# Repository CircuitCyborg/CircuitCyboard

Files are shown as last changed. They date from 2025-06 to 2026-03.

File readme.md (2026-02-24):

View the assembled board in 3D and download the most up to date files including the fully printable version at https://cad.onshape.com/documents/f318f11670ed4c30b1b2f4fc/w/6b6f3f7c04ff2543b1a0db1e/e/09f2c27e2ae763cc1f32f98d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



This is the CircuitCyboard; A 153% keyboard made for video editors or anyone who is completely insane. I decided to design this board when I started editing videos for my robotics team. It took me approximately 47 hours to complete due to having to essentially complete two keyboards to complete a single set. 

HOW LONG DID THIS KEYBOARD TAKE TO DESIGN?
This keyboard took about 47 hours to design due to being on an FTC team that made it to the World Championship along with the rest of my school and what other "life" I have.

Here's one of my mid-project updates:

March 4, 2025
It's been a while since I have really had enough time to make some progress on my HackBoard. I was able to find some time this afternoon to nearly finish the project. Here's a little overview of where I'm at, but first for those who didn't see my original plans a few months ago: I do a decent amount of video editing for my FTC team and some personal projects. Back in October during HackpadV1, I created a little 3x3 macropad with 2 rotary encoders. It has sped up my editing by probably 35%. I really like efficiency, so I started looking into the BlackMagicDesign editor keyboard.



Unfortunately, that keyboard costs $595. That's about $535 out of my price range on a normal month, and this year about $575 out of my range. When Alex announced HackpadV2 I knew I wanted to attempt to design my own version. But why stop designing when I have the exact same hardware design as BlackMagicDesign? Why not create my own unique one of a kind piece?
Introducing The CircuitCyboard: @CircuitCyborg's very own editing keyboard. It is a one of a kind piece that just so happens to resemble the Blackmagicdesign Editor Keyboard if it was a split keyboard. Why is it split you may ask? Because there are too many rows and columns for a single Raspberry Pi (Or in this case, a single Orpheus Pico). So in order to get two MCU's, Alex's requirement was that I make it a split keyboard. Now on to the update: The PCB is nearly finished. I need to add a few decorations to the silkscreen and make sure all of the stabilizer mounts will actually work (Who am I kidding, I'm not going to do that), then I think both PCB's will be ready to export. Both Cases are complete I think. I need to go through and make sure everything is 100% correctly done and finished. Today I decided I wanted to try and do the firmware in POG so that I can more easily change keys throughout the boards use. So I think firmware is complete (Enough until I get the hardware) and ready to be dropped onto the MCU's. Unfortunately, I don't believe the grants will be enough to cover everything so I may have to add some of my own funds into it. I guess that means I have to wait another month before I can buy that mic. Oh Well. It's worth it.

Here is what the original design looked like:






Here is another update now that I am getting ready to submit:

June 2, 2025
It's been another 3 months since my last update. I have almost completely redone the whole keyboard. The only things that are still the same are the base keys and their positions, and the basic idea of having a mega split using two Orpheus Picos. Since the last update I decided that instead of using a completely 3D Printed case, I wanted an acrylic top. I then redesigned the case after redesigning the PCB so that the MCU on the left half was vertical instead of horizontal so that the chord would plug in to the top instead of the side. I then added three more rotary encoders to the left half. Next I designed the case to have an acrylic top. After some thought, I am considering cutting the base of the case out of wood after I confirm it fits with a 3D Printed version. Assuming it does, I will find a nice piece of wood to cut it out of and use my robotics team's CNC router to cut it out. Next I started sourcing parts for my board. At this point I still haven't ordered parts yet, but I am trying my best to not order any parts directly from AliExpress because I do not trust that site or any of its sibling sites. Do to this, parts may cost a little more for me, but occasionally, I can find better quality parts as well from Amazon over what can be found at AliExpress. I think that's all for this update. Signing off for now, Circuitcyborg.

Here is what the semi-final design looks like:













I have now spent the last few days putting together all of the files and getting pricing down and finalizing part selections for the BOM and to create my Repo. Next up is the info for the firmware.

Firmware was kept simple for this because although editing the firmware on my macropad has been relatively simple, I want an even simpler way to edit the firmware for this. Introducing POG, a firmware editor/writer for keyboards based off of KMK. All you need to do is install POG on your device and install the firmware I have provided onto your Raspberry Pi's, then you will be able to edit the keyboard functions from within POG.

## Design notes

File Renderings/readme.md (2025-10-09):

Renderings of the CircuitCyboard 153% Keybaord
























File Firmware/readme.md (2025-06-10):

Firmware was kept simple for this because although editing the firmware on my macropad has been relatively simple, I want an even simpler way to edit the firmware. Introducing POG, a firmware editor/writer for keyboards based off of KMK. I have not tested it yet, but the idea is that anyone can install this firmware on it, then install POG and easily be able to edit the firmware on it. I'll update once I have the time to test this theory.





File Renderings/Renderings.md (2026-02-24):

Renderings of the CircuitCyboard 153% Keybaord


























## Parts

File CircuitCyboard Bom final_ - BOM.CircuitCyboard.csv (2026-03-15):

Total Per Part Category |  | Quantity Needed | Total Cost Pre-Tax | Component | Supplier | Link
$76.15 | PCB | 1 | $36.65 | Left PCB | JLCPCB | N/A
 |  | 1 | $39.50 | Right PCB | JLCPCB | N/A
$45.96 | Switches - $0.50/Switch | 2 | $22.98 | Gateron G Blue Pro 3.0 Switches | Aliexpress | https://www.aliexpress.us/item/3256804371339613.html?
$12.77 | Fasteners - Total $15 | 1 | $5.48 | GSJ Threaded Heat Set Inserts | Aliexpress | https://www.aliexpress.us/item/3256804189121253.html?
 |  | 1 | $7.29 | M3 Button Head Socket Cap Bolts | Aliexpress | https://www.aliexpress.us/item/3256806973435795.html?
$11.69 | Keycaps - $25 | 1 | $7.80 | Keycaps 126 Keys Cherry Profile | Aliexpress | https://www.aliexpress.us/item/3256807135386098.html?
 |  | 1 | $3.89 | 24 Pc DSA Profile 1u keycaps | Aliexpress | https://www.aliexpress.us/item/3256807298018561.html?
$23.77 | Stabilizers - $20 | 1 | $23.77 | Durock Stabilizers V3 80% Kit | Aliexpress | https://www.aliexpress.us/item/3256802006071565.html?
$11.81 Including Shipping | Misc Electronics - $15 | 1 | $3.17 | Alpsalpine EC11E Rotary Encoder | Aliexpress | https://www.aliexpress.us/item/3256805796819763.html?
 |  | 2 | $8.64 | LGE 1N4148 Diodes | Aliexpress | https://www.aliexpress.us/item/3256802153601411.html?
N/A | MCU | 2 | N/A | Orpheus Picos | Hack Club | N/A
$9.95 | Other Parts | 1 | $9.95 | Polycarbonate Sheet 12x18 1/16" | Amazon | https://www.amazon.com/Polycarbonate-Plastic-Robotics-Industrial-Shatterproof/dp/B07MQTDF4R
N/A | Case | 1 | N/A | Left Case Base - 3D Printed | CircuitCyborg | https://github.com/CircuitCyborg/CircuitCyboard/blob/main/Case/Left/CircuitCyboard_Left_Case_Base.step
 |  | 1 | N/A | Right Case Base - 3D Printed | CircuitCyborg | https://github.com/CircuitCyborg/CircuitCyboard/tree/main/Case/Right/CircuitCyboard_Right_Case_Base.step
 |  | 1 | N/A | Left Case Top - Polycarbonate | CircuitCyborg | https://github.com/CircuitCyborg/CircuitCyboard/blob/main/Case/Left/Left_Plate_Acrylic.dxf
 |  | 1 | N/A | Right Case Top - Polycarbonate | CircuitCyborg | https://github.com/CircuitCyborg/CircuitCyboard/blob/main/Case/Right/Right_Plate_Acrylic.dxf
Price By Supplier - Includes Shipping to My Location
Aliexpress | PCBWay | Amazon
$108.00 | $76.15 | $10.77
Amount Paid By Hack Club: | $194.84
Amount Paid By CircuitCyborg | Any extra shipping/fees

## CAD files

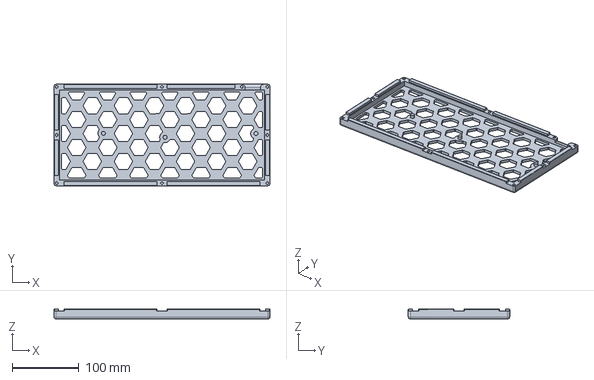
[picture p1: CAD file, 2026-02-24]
Case/Left/CircuitCyboard_Left_Case_Base.step
322.5 x 151.5 x 15.0 mm

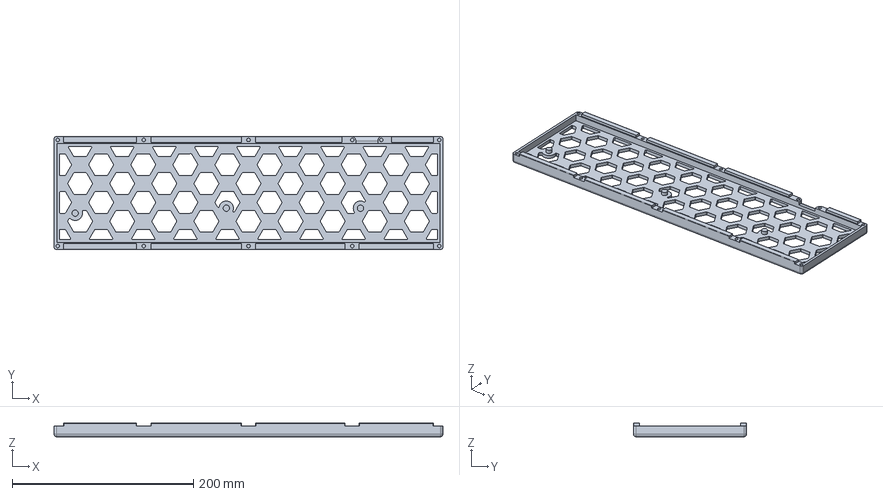
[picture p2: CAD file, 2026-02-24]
Case/Right/CircuitCyboard_Right_Case_Base.step
429.0 x 125.0 x 15.0 mm

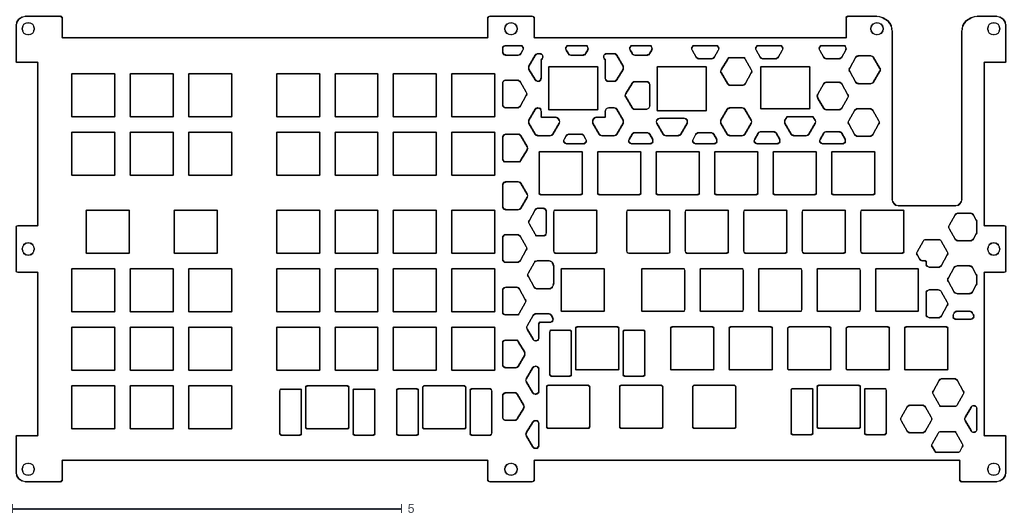
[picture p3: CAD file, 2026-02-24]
Case/Left/Left_Plate_Acrylic.dxf
12.7 x 5.97

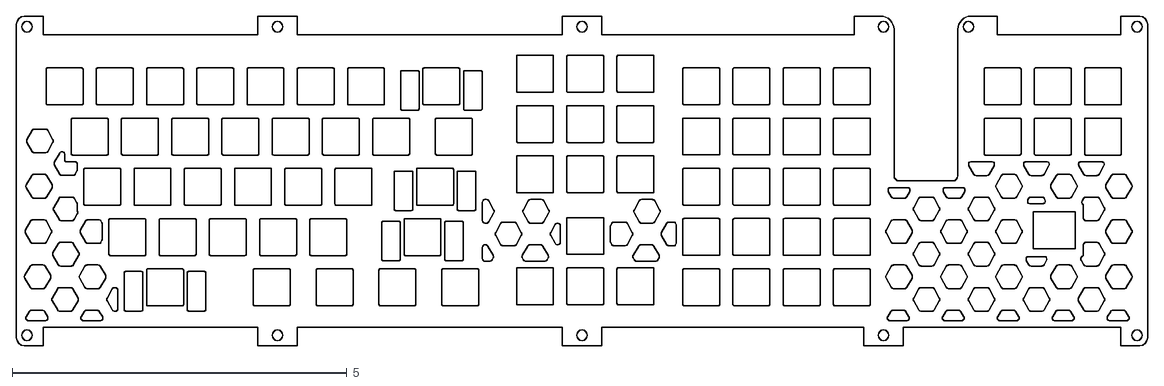
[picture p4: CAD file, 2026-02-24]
Case/Right/Right_Plate_Acrylic.dxf
16.9 x 4.92

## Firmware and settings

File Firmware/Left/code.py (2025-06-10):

# Main Keyboard Configuration - v1.0.0
import board
import pog
# check if we just want to run the coord_mappping Assistant
if pog.coordMappingAssistant:
    from coordmaphelper import CoordMapKeyboard
    if __name__ == '__main__':
        CoordMapKeyboard().go()
    print("Exiting Coord Mapping Assistant Because of an error")
else:
    from kb import POGKeyboard
    # set the required features for you keyboard and keymap
    # add custom ones in the kb.py

    keyboard = POGKeyboard(features=pog.kbFeatures)

    # manage settings for our modules and extensions here
    keyboard.tapdance.tap_time = 200

    # Keymap
    import keymap
    keyboard.keymap = keymap.keymap

    # Encoder Keymap if available
    if pog.hasEncoders:
        keyboard.encoder_handler.map = keymap.encoderKeymap

    # Execute the keyboard loop
    if __name__ == '__main__':
        keyboard.go()

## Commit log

2025-10-09 Add files via upload
    Final BOM
    [BOM.CircuitCyboard-Final.csv]
2025-10-09 Delete BOM.CircuitCyboard_Final.csv
    Delete Original BOM
    [BOM.CircuitCyboard_Final.csv]
2025-10-09 Update readme.md
    Upload Rendering of Final Board
2025-10-09 Add files via upload
    Add PCB Project Files
    [CircuitCyboard-Right.kicad_pcb, CircuitCyboard-Right.kicad_sch, CircuitCyboard.kicad_pcb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]
2025-10-09 Uploading knob and board with knob renderings
2025-10-16 Update BOM with new part details and links
    More correction/changes in a second
    [BOM.CircuitCyboard-Final.csv]
2025-10-16 Update BOM with new pricing
    [BOM.CircuitCyboard-Final.csv]
2025-10-16 Update BOM with new part details and links
    [BOM.CircuitCyboard-Final.csv]
2025-10-16 Update BOM with new parts and pricing details
    [BOM.CircuitCyboard-Final.csv]
2025-10-16 Update BOM with additional components and links
    [BOM.CircuitCyboard-Final.csv]
2025-10-16 add updated BOM
    [CircuitCyboard Bom final_ - BOM.CircuitCyboard.csv]
2025-10-16 Update CircuitCyboard Bom final_ - BOM.CircuitCyboard.csv
    [CircuitCyboard Bom final_ - BOM.CircuitCyboard.csv]
2026-02-24 Update Left Case Files
    [CircuitCyboard_Left_Case_Base.step, Left_Plate_Acrylic.dxf]
2026-02-26 Update BOM with Correct links
    [CircuitCyboard Bom final_ - BOM.CircuitCyboard.csv]
2026-03-06 Update BOM with correct/current pricing
    [CircuitCyboard Bom final_ - BOM.CircuitCyboard.csv]
2026-03-15 Update BOM with new pricing and supplier links
    [CircuitCyboard Bom final_ - BOM.CircuitCyboard.csv]
